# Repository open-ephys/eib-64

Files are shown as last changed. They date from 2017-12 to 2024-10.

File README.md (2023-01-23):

# EIB-64
64-channel electrode interface board (EIB) with electrical and optical
stimulation. Designed for small animal (e.g. mouse) tetrode electrophysiology.
Compatible with [ONIX 64-Channel Headstage](https://github.com/open-ephys/onix-headstage-64) and [Shuttle
Drives](https://open-ephys.org/shuttledrive).

See [this spreadsheet](https://docs.google.com/spreadsheets/d/1WYDymxNqGRtFPxn69H9JzeMgePpXcFSPHiWJYBE0lu4/edit?usp=sharing) for channel map 

- 64x electrophysiology channels
- 2x optical stimulation outputs
- 1x electrical stimulator output

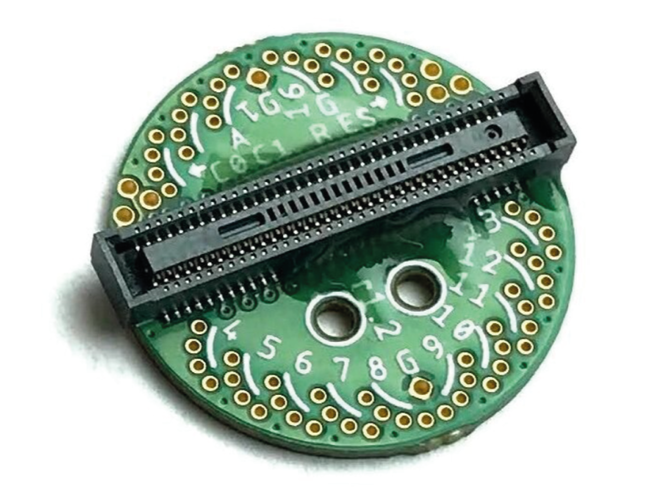
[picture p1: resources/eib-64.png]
EIB-64 revision 1.2


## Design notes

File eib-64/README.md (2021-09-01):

# EIB-64 PCB
Circuit design and manufacturing files for EIB-64.

## Bill of Materials
The BOM is located on [this google
sheet](https://docs.google.com/spreadsheets/d/1vJ3K68Tzy18eBl7zj2bWWYmF2zrh3wpJbKvRicM5Wa0/edit?usp=sharing)

## Pinout
The EIB pinout (ADC input mapping, stimulation connections, etc) is located on
[this google
sheet](https://docs.google.com/spreadsheets/d/11wRDYOqHN5lPb03yUdfXfK0zvaDYsVetplaNK-R90Gg/edit#gid=0)

## Tetrode Connectorization
This EIB uses Neuralynx ["small" gold
pins](https://neuralynx.com/hardware/small-eib-pins) to attach tetrode wires.
Usage instructions are provided in the [Neuralynx EIB pin
Manual](https://neuralynx.com/documents/EIB%20Pins%20Manual.pdf).

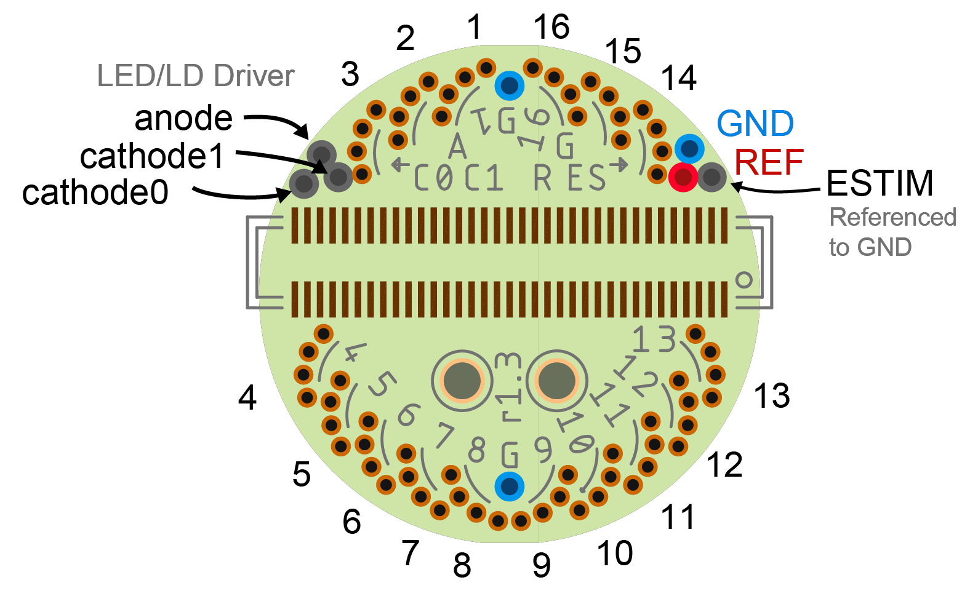
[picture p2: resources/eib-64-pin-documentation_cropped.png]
EIB-64 pinout


## Manufacturing Requirments
- 4 layer PCB (outer layers provide sheilding)
- 0.6-0.8 mm total thickness
- Immersion gold plating (ENIG) is required. 
- In order for the gold pins to properly fit in the designated vias, they must
  have a _plated_ inner diameter of 12±2 mil (0.3048±0.0508 mm). 

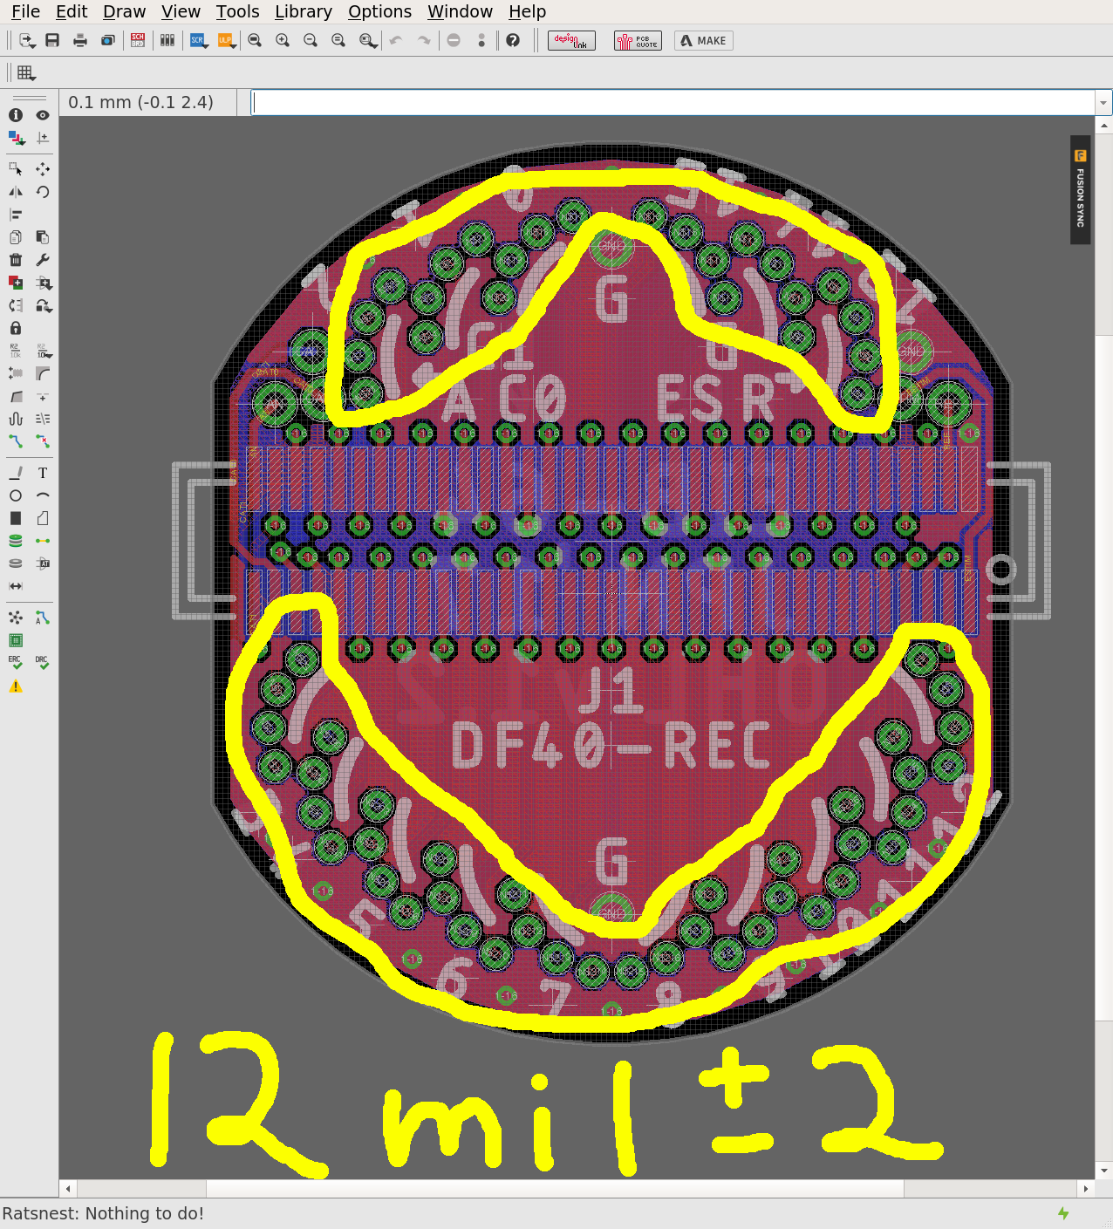
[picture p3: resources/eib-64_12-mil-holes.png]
Required via diametersEIB-64 pinout


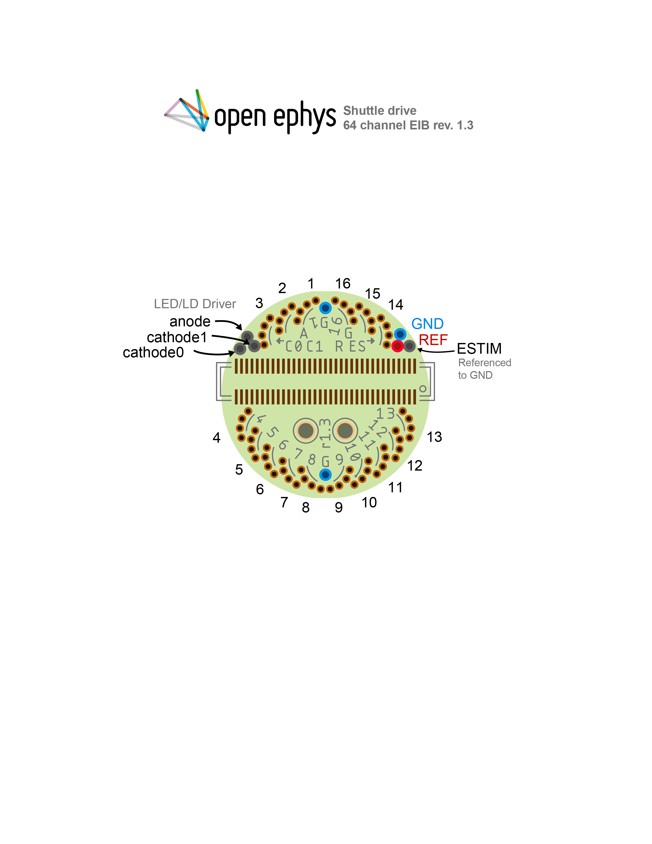
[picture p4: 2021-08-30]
resources/eib-64-pin-documentation.png

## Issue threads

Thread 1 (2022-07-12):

Mismatch between EIB pdf and linked mapping in doc

ablot, 2022-07-12:
In the onix documentation and in the readme.md the pin mapping points to this google doc: https://docs.google.com/spreadsheets/d/11wRDYOqHN5lPb03yUdfXfK0zvaDYsVetplaNK-R90Gg

In the google document, DF40 pin 37 is TT4B but in this repository, DF40 pin 37 is  LRG_GP SHLD_A. This is true for both eib-64/eib-64/eib-64.sch and the pdf version.

It might be a version issue. The pdf and sch files indicate REV 1.3 and the mapping google doc rev 1.2. If that's the case, where can I find the rev1.2 schematics?

ablot, 2022-07-12:
There is an other issue on the google doc. The nanoZ pin for TT14C is replaced by some wrongly copy/pasted text ("The EIB pinout (ephys input mapping, stimulation connections, etc) is located on this google sheet")

jonnew, 2022-07-22:
- Fixed the nanoZ TT14C copy/paste error
- Added tag for rev. 1.2 that went into production (https://github.com/open-ephys/eib-64/releases/tag/rev-1.2)
- I believe your EIB should be rev 1.2 (you can check the silk screen) and the spreadsheet mapping should now be correct.

Closed 2022-07-22.

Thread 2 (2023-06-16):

About 32-ch EIB for lack of a better place

ChucklesOnGitHub, 2023-06-16:
Regarding EIBs in general (see those available https://open-ephys.org/drive-implant/64-channel-eib-lyfw2)

- Hole size should be consistent across EIBs (at least of same size and application)
- 32-ch EIB does not have labels on the bottom side which make tetrode insertion and pinning much easier

jonnew, 2024-03-01:
Can you explain the second point, I don't understand it.

ChucklesOnGitHub, 2024-03-01:
This was me porting your comments from Discord during TENSS last year, so no idea what you were facing exactly :/

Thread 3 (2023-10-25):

64ch EIB schematics for channel mapping not in main

ChucklesOnGitHub, 2023-10-25:
User pointed out the following:
File [eib-64.brd](https://github.com/open-ephys/eib-64/blob/main/eib-64/eib-64.brd) does not match the [channel map](https://docs.google.com/spreadsheets/d/1WYDymxNqGRtFPxn69H9JzeMgePpXcFSPHiWJYBE0lu4/edit#gid=0).

- On one side the file shows pad 69 routing to a channel/pin and pad 70 going to the reference (when the channel map lists pin 69 as a reference and pin 70 as the ground)

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

- On the other side it likewise shows pad 36 going to an anode (which matches the channel map), but pad 37 going to ground (when the channel map routes it to a channel/pin).

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

On a physical EIB the routing is correct with regards to the channel map: REF is connected to pin 69 and GND to pin 70. - i've now realized what it is, I must have been looking at a r1.2

It would seem the file does not match the boards?

This made me realize the channel map has to be updated to read v1.3 and have picture of EIB v1.3 since the current production version is 1.3 and not 1.2 - I can handle this but not the above.

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

ChucklesOnGitHub, 2023-10-25:
I just realized the channel map for r1.3 is a different one, and that would solve it. Can you confirm so I can update the channel map google sheets?
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

jonnew, 2023-10-25:
We should deprecate 1.3 because it was never put in production (not that is
compatible with headstage rev 1.4, which also was never produced)

On Wed, Oct 25, 2023 at 11:26 AM Ceci Herbert ***@***.***>
wrote:

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

jonnew, 2024-03-01:
In any case, I think we need to role back HEAD commit on this repo to 1.2 since its all that will ever be made. Additionally, we need a more easy to follow pin mapping picture which has a front view image of the headstage with each of the DF40 pins labeled and each individual pin hole labelled.

ChucklesOnGitHub, 2024-03-08:
hi @jonnew I have in my hand an EIB that says r1.3, which as far as I understand is the same as r1.2 with an extra hole

ChucklesOnGitHub, 2024-03-20:
The correct production files are in the corresponding branch, the issue is solved by merging.

Just for reassurance, here is the correct mapping file of the EIB that is currently in production.
[eib-64_schematic.pdf](https://github.com/open-ephys/eib-64/files/14671609/eib-64_schematic.pdf)

and it matches both current production versions of onix hs-64 and low-profile-hs-64-spi
[hs-64-spi - schematic.pdf](https://github.com/open-ephys/eib-64/files/14671615/hs-64-spi.-.schematic.pdf)
[headstage-64_schematic.pdf](https://github.com/open-ephys/eib-64/files/14671616/headstage-64_schematic.pdf)

I have updated the channel map google sheet accordingly and plan on making it more clear with updated pictures

ChucklesOnGitHub, 2024-03-22:
For users to know which is the current manufactured version in case they want to access schematics or cad files, the following need to be main:
Repo: eib-64 - Branch: hw-dev-rev1.3. Tag rev1.3
Repo: onix-headstage-64 - Branch: rev-1.3B Tag rev-1.3B

- Additionally, the schematic information table inside file "headstage-64_schematic.pdf" in repo onix-headstage-64 mistakenly reads "1.2B", and should read "1.3B" otherwise it is impossible to know the version with the file alone

Outstanding on unifying this topic across repos is:
- have a public repo with the current manufactured files for nanoz adapter 1.0 with the tag rev1.0
- tag the adapter-64 with tag rev1.0

jonnew, 2024-10-30:
As of right now:

- main is now the production branch
- The revision 1.3 release points to the current tip of main
- The incompatible version was move to rev-1.4-dev branch

@ChucklesOnGitHub please close this issue if this takes care of the problem

ChucklesOnGitHub, 2024-10-31:
The original issue that pertains to this repo is solved, thank you.

I have put other related issues in their respective repos:
- https://github.com/open-ephys/adapter-hirose-omnetics-64/issues/2
- https://github.com/open-ephys/onix-headstage-64/issues/4
- https://github.com/open-ephys/onix-headstage-64/issues/3

Outstanding since I don't have a repo in which to open an issue:
- have a public repo with the current manufactured files for nanoz adapter 1.0 with the tag rev1.0

Closed 2024-10-31.

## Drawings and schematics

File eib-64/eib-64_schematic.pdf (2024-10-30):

A

A

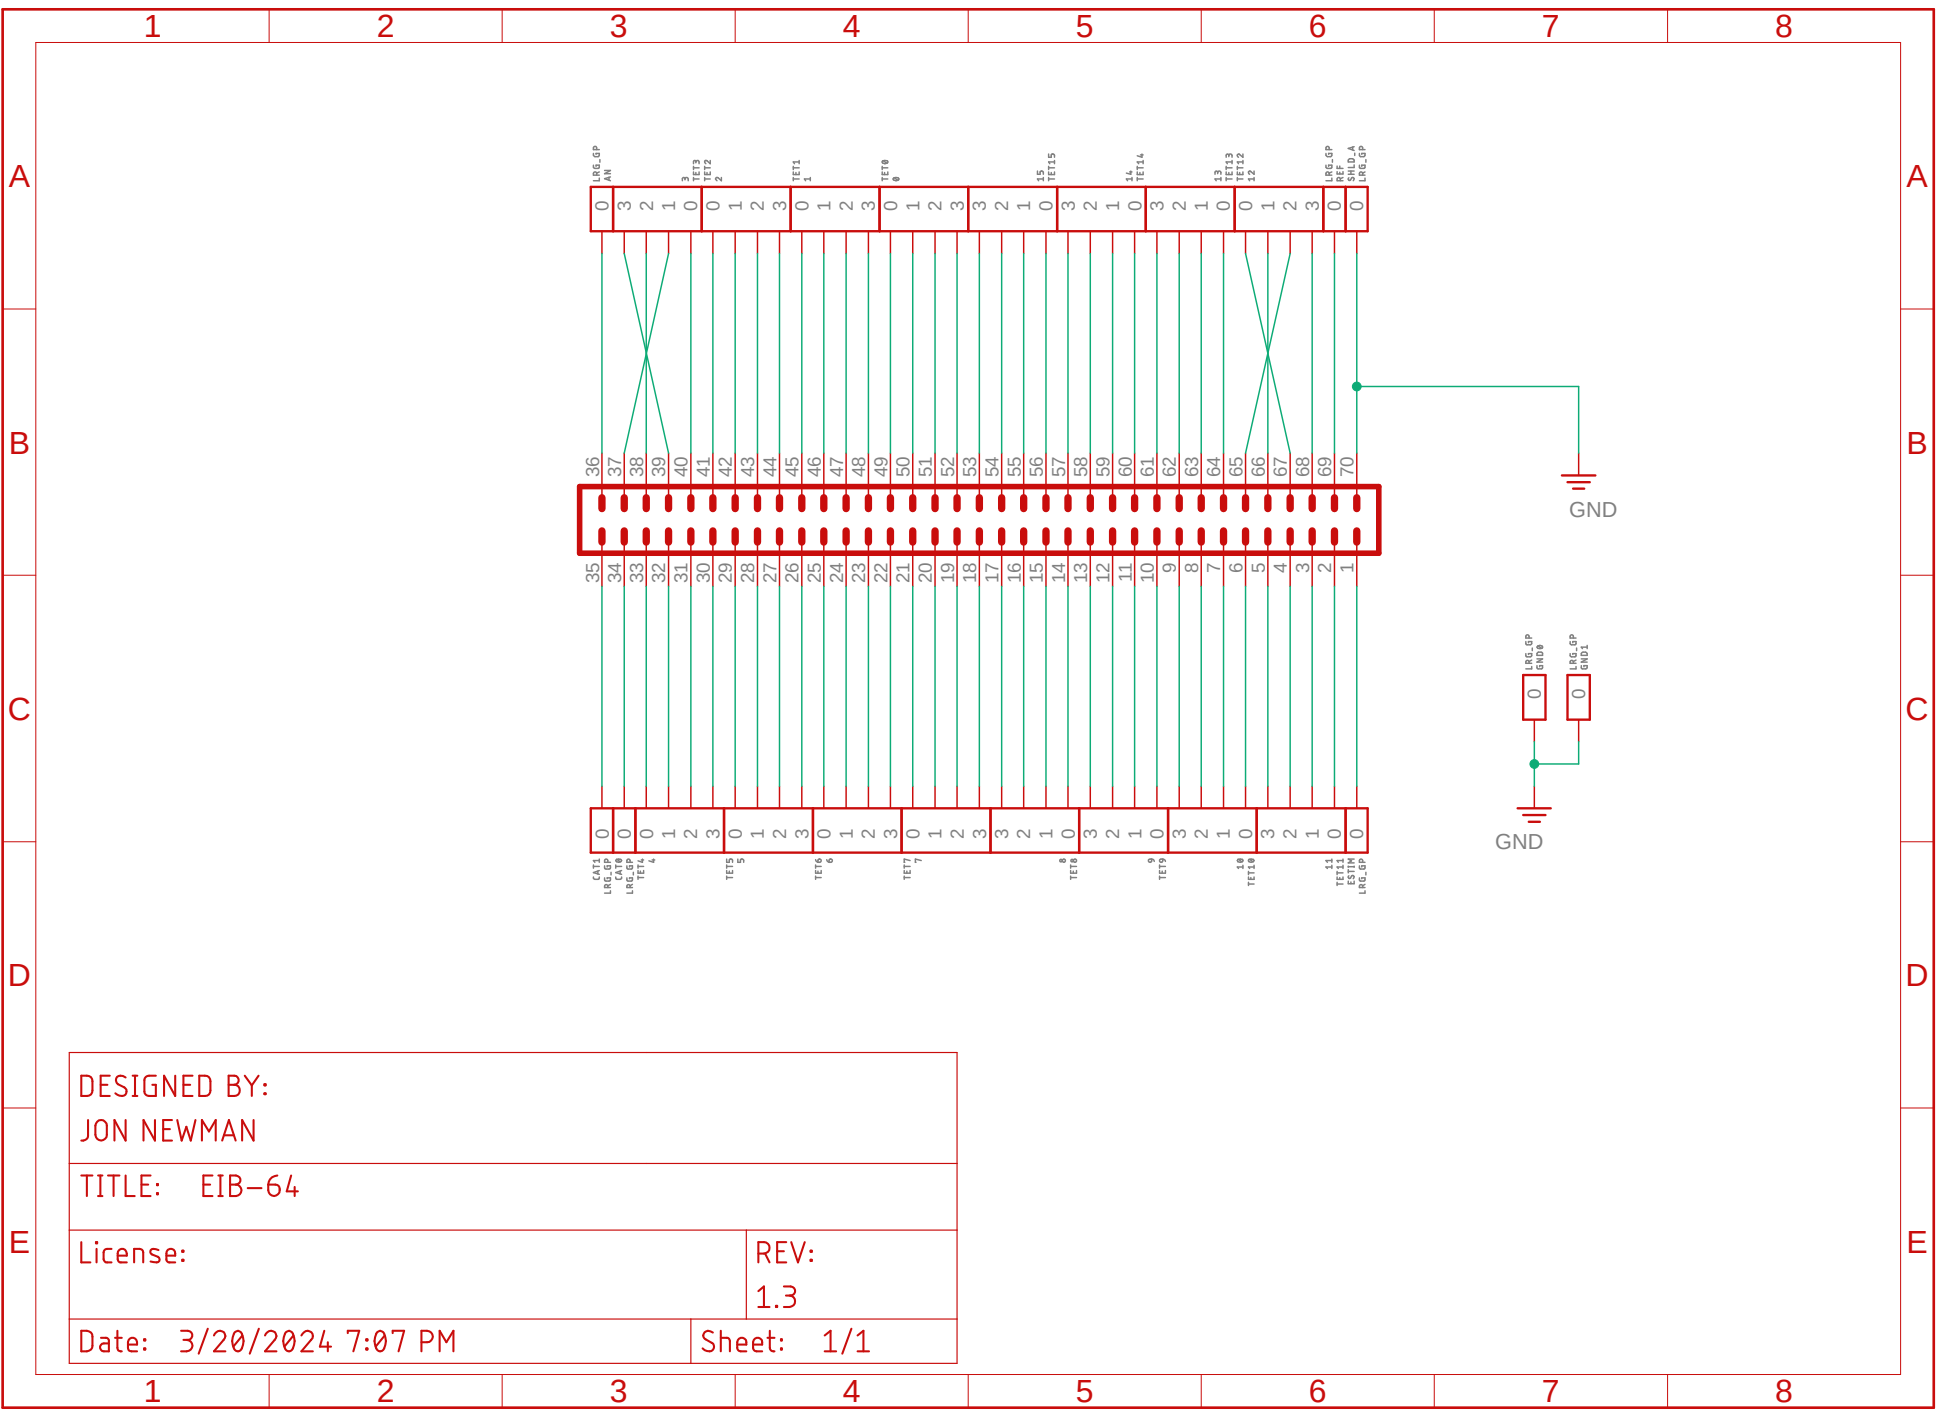
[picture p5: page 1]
GND; GND ⁰

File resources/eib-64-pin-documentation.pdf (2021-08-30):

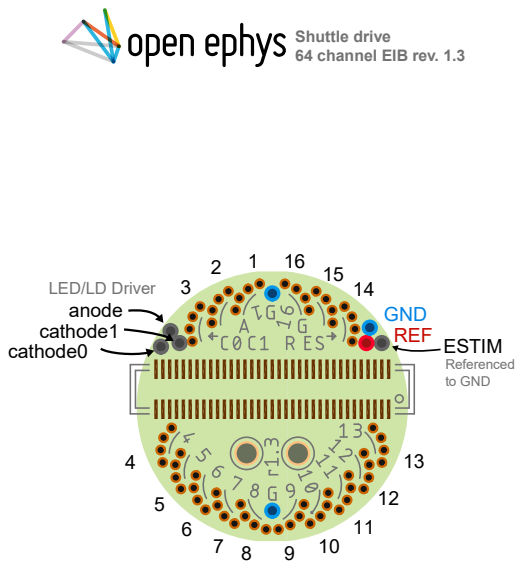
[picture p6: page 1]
GND REF ESTIM; cathode0; cathode1; anode; LED/LD Driver; Referenced to GND

Shuttle drive
64 channel EIB rev. 1.3

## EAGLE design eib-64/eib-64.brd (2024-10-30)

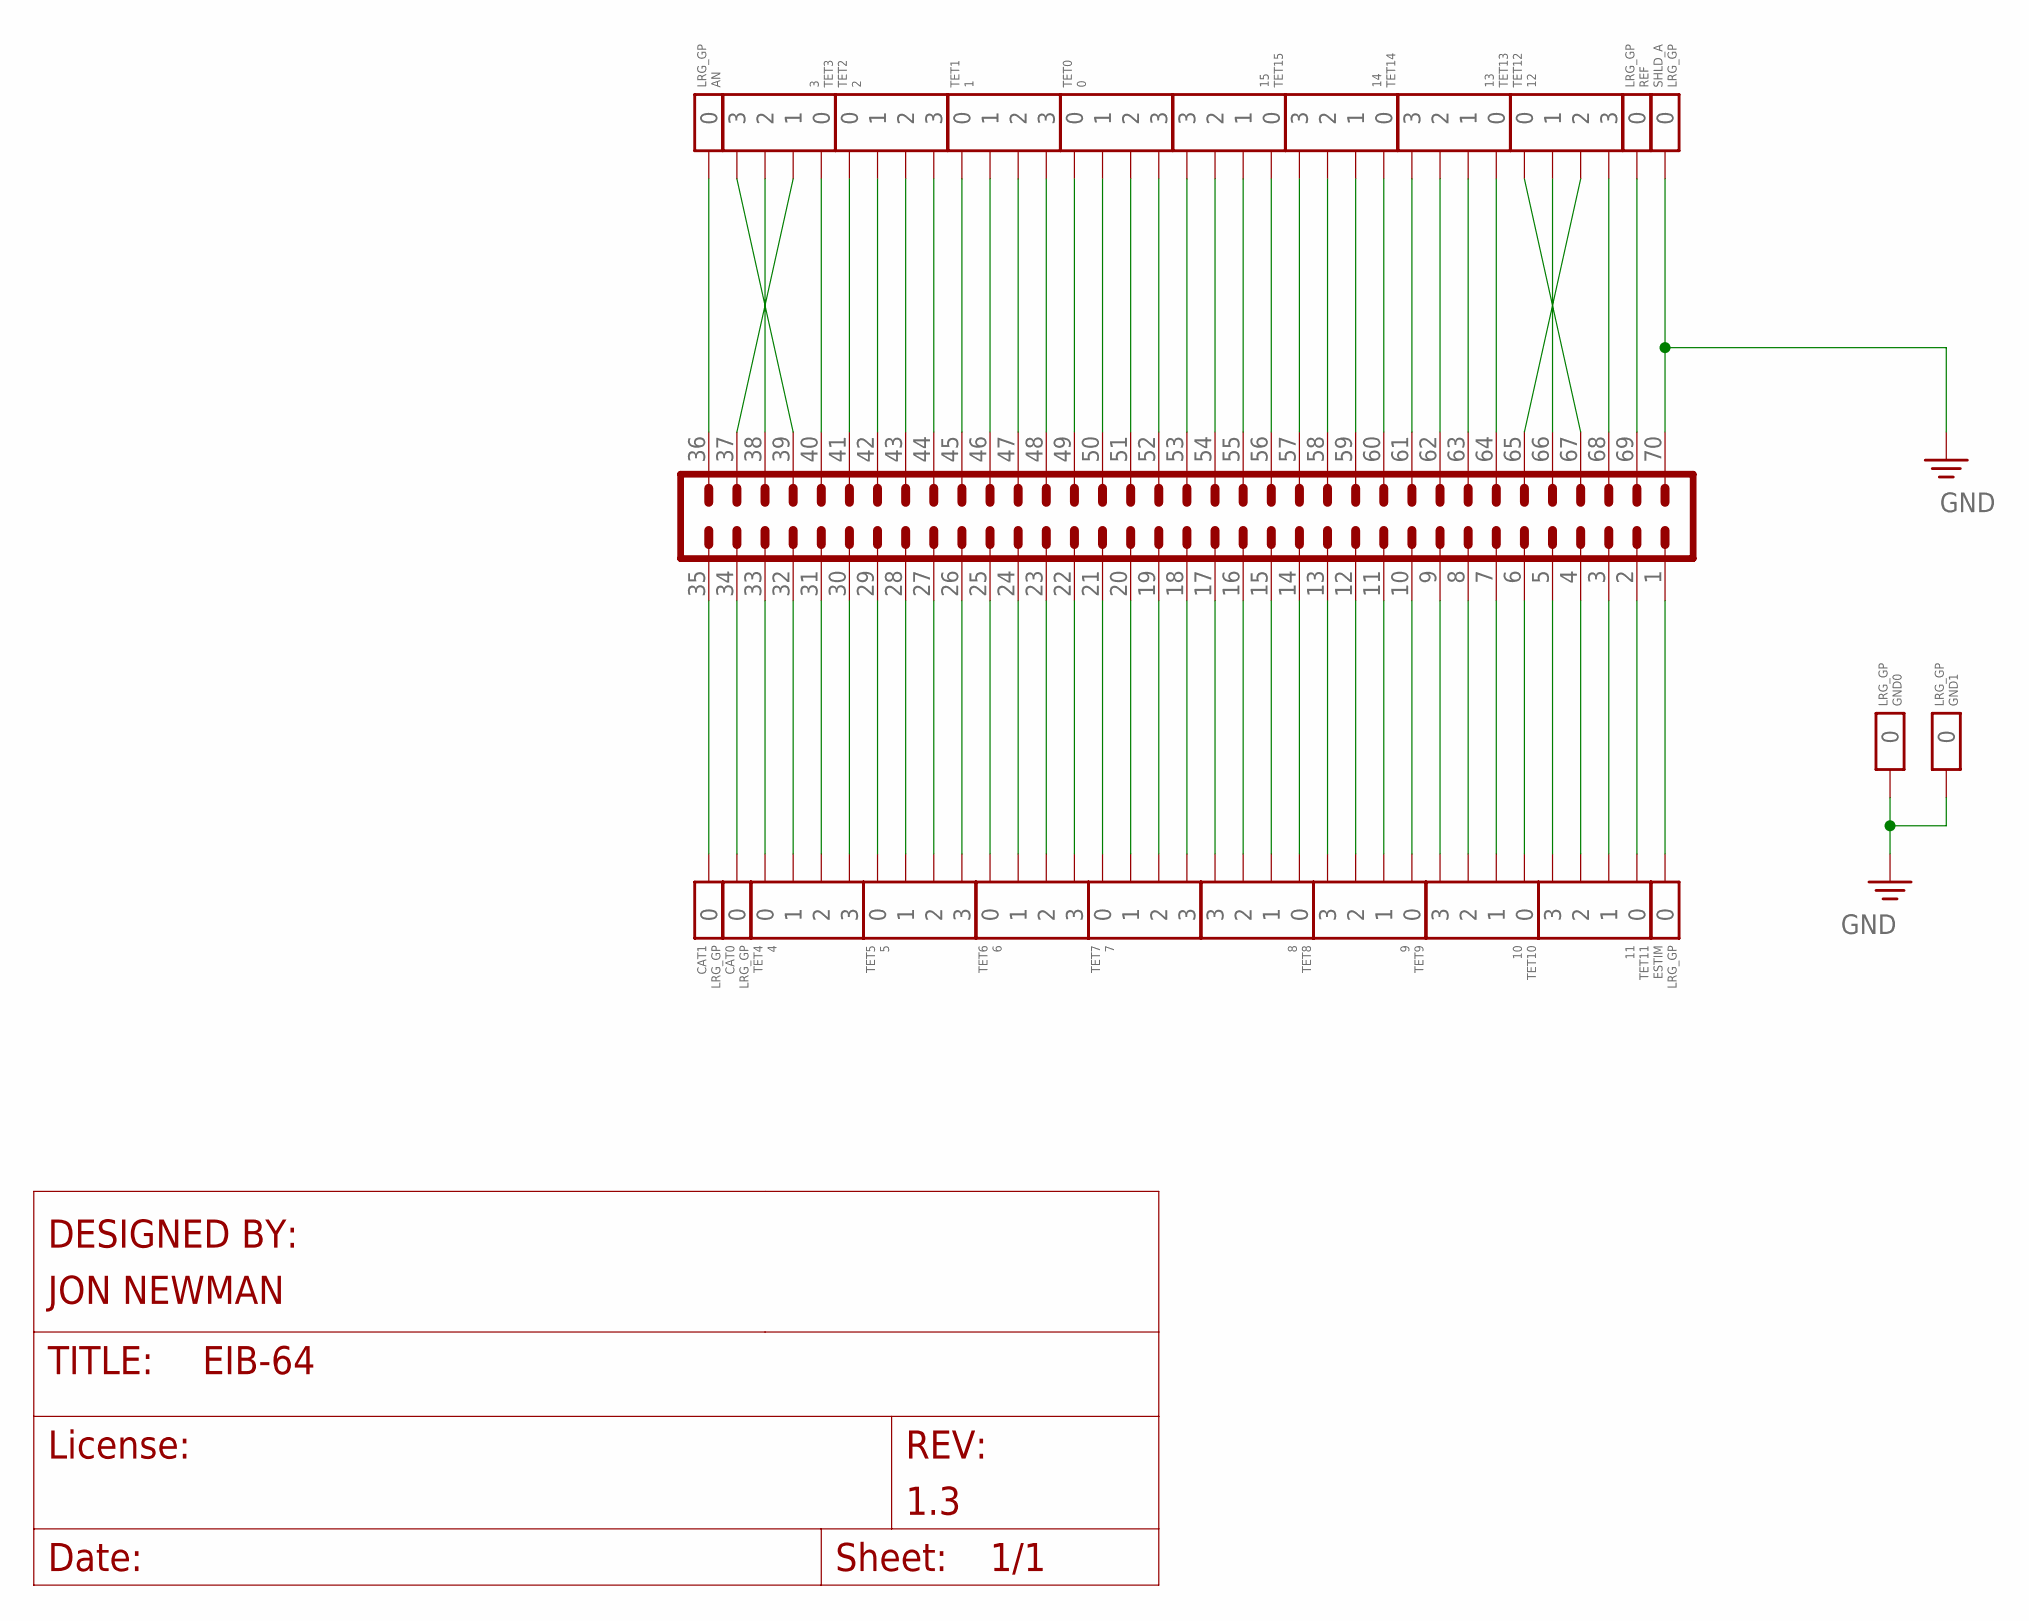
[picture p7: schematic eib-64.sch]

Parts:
AN: LRG_GP; GOLDPIN_0.5ID_0.7OD
CAT0, CAT1: LRG_GP; GOLDPIN_0.5ID_0.7OD
ESTIM: LRG_GP; GOLDPIN_0.5ID_0.7OD
GND0, GND1: LRG_GP; GOLDPIN_0.5ID_0.7OD
J1: DF40-REC; DF40-70REC
REF: LRG_GP; GOLDPIN_0.5ID_0.7OD
SHLD_A: LRG_GP; GOLDPIN_0.5ID_0.7OD
TET0: 0; TETRODE_0.3ID_LINEAR_MOUSE
TET1: 1; TETRODE_0.3ID_LINEAR_MOUSE
TET2: 2; TETRODE_0.3ID_LINEAR_MOUSE
TET3: 3; TETRODE_0.3ID_LINEAR_MOUSE
TET4: 4; TETRODE_0.3ID_LINEAR_MOUSE
TET5: 5; TETRODE_0.3ID_LINEAR_MOUSE
TET6: 6; TETRODE_0.3ID_LINEAR_MOUSE
TET7: 7; TETRODE_0.3ID_LINEAR_MOUSE
TET8: 8; TETRODE_0.3ID_LINEAR_MOUSE
TET9: 9; TETRODE_0.3ID_LINEAR_MOUSE
TET10: 10; TETRODE_0.3ID_LINEAR_MOUSE
TET11: 11; TETRODE_0.3ID_LINEAR_MOUSE
TET12: 12; TETRODE_0.3ID_LINEAR_MOUSE
TET13: 13; TETRODE_0.3ID_LINEAR_MOUSE
TET14: 14; TETRODE_0.3ID_LINEAR_MOUSE
TET15: 15; TETRODE_0.3ID_LINEAR_MOUSE

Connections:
AN: AN.P$1, J1.36
CAT0: CAT0.P$1, J1.34
CAT1: CAT1.P$1, J1.35
ESTIM: ESTIM.P$1, J1.1
GND: GND0.P$1, GND1.P$1, J1.70, SHLD_A.P$1
unnamed: J1.68, TET12.3
unnamed: J1.65, TET12.2
unnamed: J1.66, TET12.1
unnamed: J1.67, TET12.0
unnamed: J1.64, TET13.0
unnamed: J1.63, TET13.1
unnamed: J1.62, TET13.2
unnamed: J1.61, TET13.3
unnamed: J1.60, TET14.0
unnamed: J1.59, TET14.1
unnamed: J1.58, TET14.2
unnamed: J1.57, TET14.3
unnamed: J1.56, TET15.0
unnamed: J1.55, TET15.1
unnamed: J1.54, TET15.2
unnamed: J1.53, TET15.3
unnamed: J1.52, TET0.3
unnamed: J1.51, TET0.2
unnamed: J1.50, TET0.1
unnamed: J1.49, TET0.0
unnamed: J1.48, TET1.3
unnamed: J1.47, TET1.2
unnamed: J1.46, TET1.1
unnamed: J1.45, TET1.0
unnamed: J1.44, TET2.3
unnamed: J1.43, TET2.2
unnamed: J1.42, TET2.1
unnamed: J1.41, TET2.0
unnamed: J1.40, TET3.0
unnamed: J1.39, TET3.3
unnamed: J1.38, TET3.2
unnamed: J1.37, TET3.1
unnamed: J1.5, TET11.3
unnamed: J1.4, TET11.2
unnamed: J1.3, TET11.1
unnamed: J1.2, TET11.0
unnamed: J1.33, TET4.0
unnamed: J1.32, TET4.1
unnamed: J1.31, TET4.2
unnamed: J1.30, TET4.3
unnamed: J1.29, TET5.0
unnamed: J1.28, TET5.1
unnamed: J1.27, TET5.2
unnamed: J1.26, TET5.3
unnamed: J1.25, TET6.0
unnamed: J1.24, TET6.1
unnamed: J1.23, TET6.2
unnamed: J1.22, TET6.3
unnamed: J1.21, TET7.0
unnamed: J1.20, TET7.1
unnamed: J1.19, TET7.2
unnamed: J1.18, TET7.3
unnamed: J1.17, TET8.3
unnamed: J1.16, TET8.2
unnamed: J1.15, TET8.1
unnamed: J1.14, TET8.0
unnamed: J1.13, TET9.3
unnamed: J1.12, TET9.2
unnamed: J1.11, TET9.1
unnamed: J1.10, TET9.0
unnamed: J1.9, TET10.3
unnamed: J1.8, TET10.2
unnamed: J1.7, TET10.1
unnamed: J1.6, TET10.0
REF: J1.69, REF.P$1

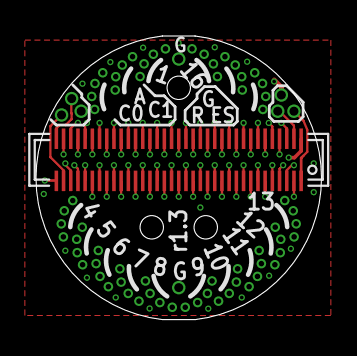
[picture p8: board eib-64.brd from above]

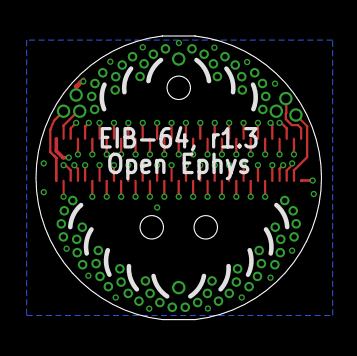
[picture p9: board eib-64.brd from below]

Board: 4 copper layers, 15.9 x 15.8 mm, 25 parts (8 on the bottom side), 70 nets.

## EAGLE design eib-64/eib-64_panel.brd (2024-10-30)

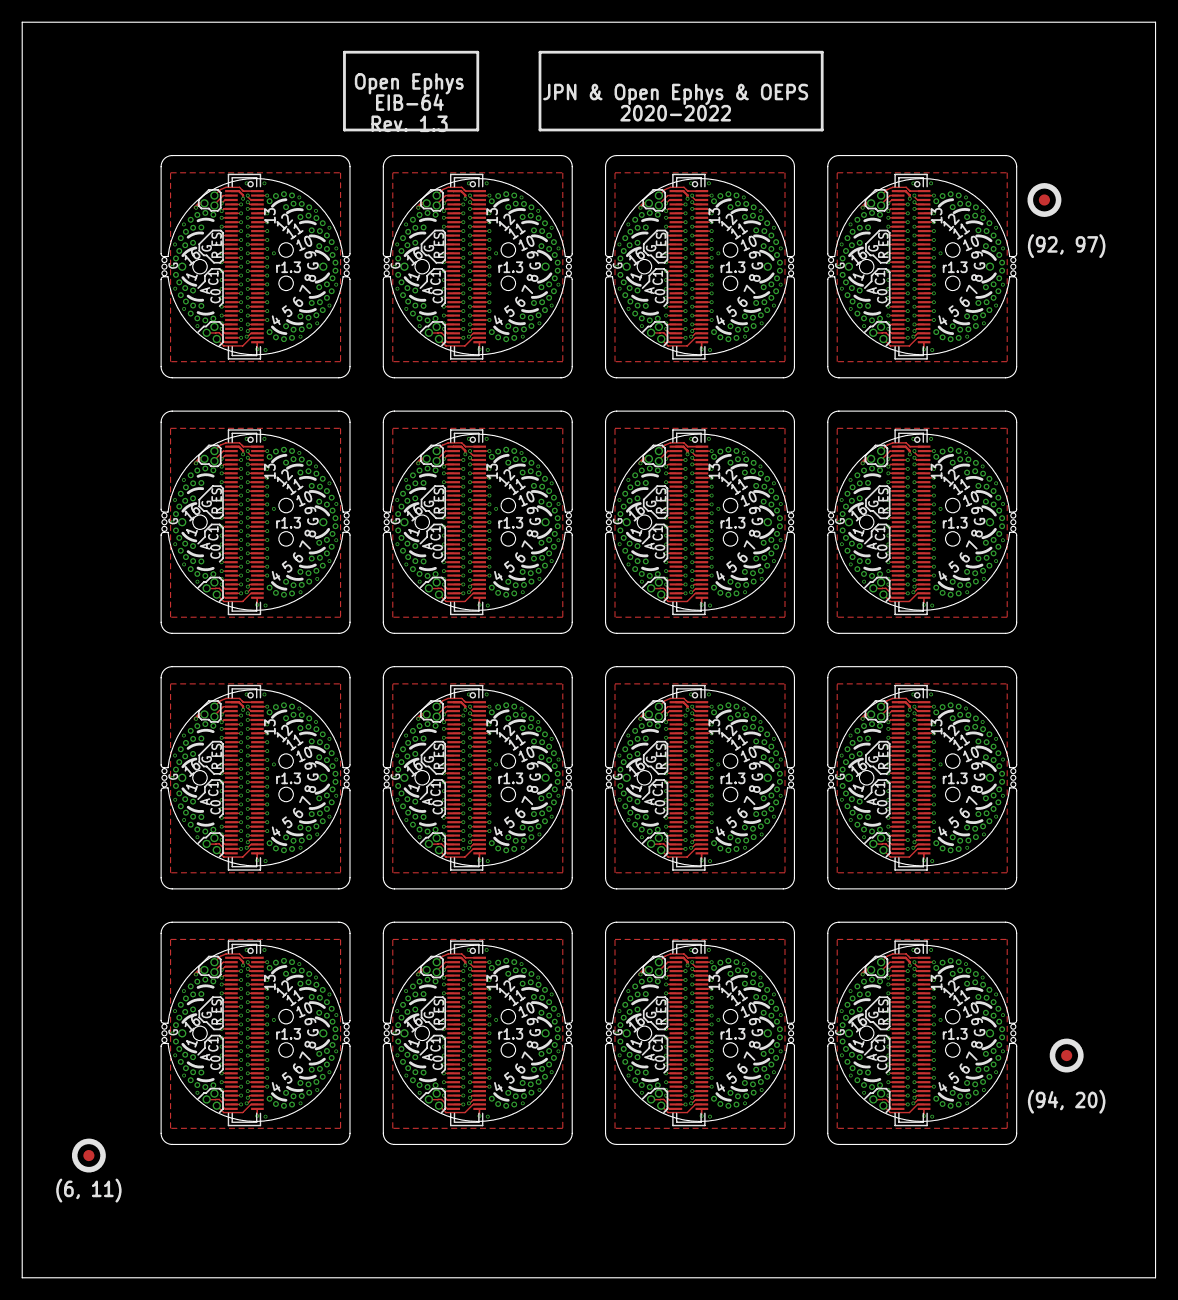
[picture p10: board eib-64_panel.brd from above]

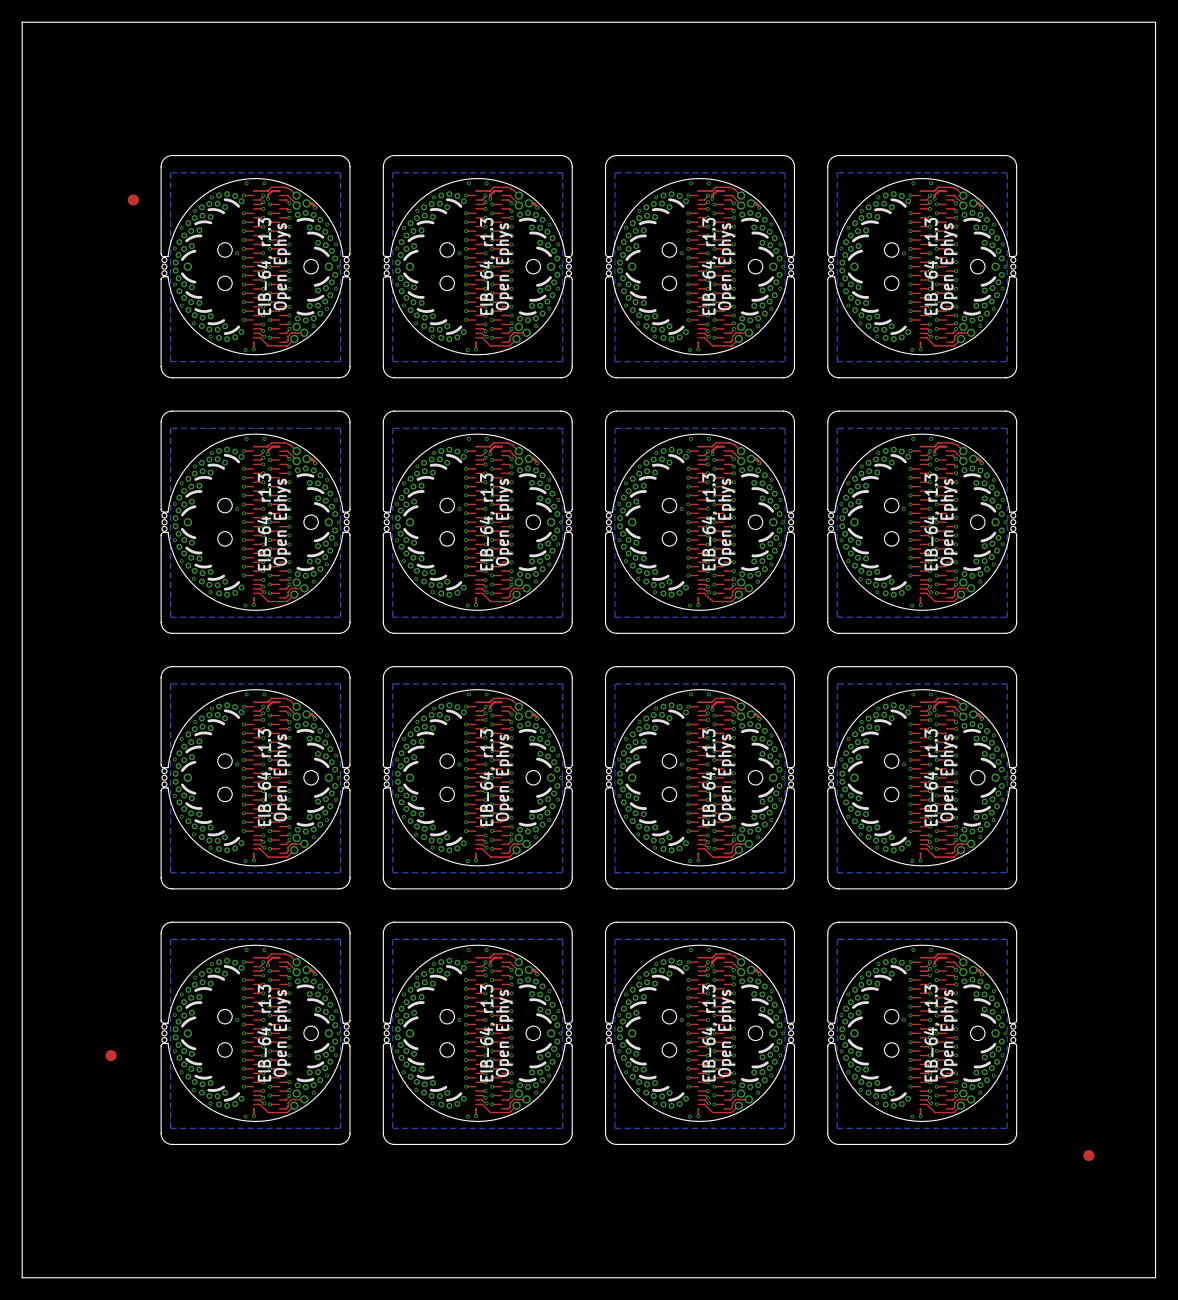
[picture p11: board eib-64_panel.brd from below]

Board: 4 copper layers, 102.0 x 113.0 mm, 403 parts (128 on the bottom side), 1120 nets.

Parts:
AN, AN1, AN2, AN3, AN4, AN5, AN6, AN7, AN8, AN9, AN10, AN11, AN12, AN13, AN14, AN15: LRG_GP; GOLDPIN_0.5ID_0.7OD
CAT0, CAT1, CAT2, CAT3, CAT4, CAT5, CAT6, CAT7, CAT8, CAT9, CAT10, CAT11, CAT12, CAT13, CAT14, CAT15, CAT16, CAT17, CAT18, CAT19, CAT20, CAT21, CAT22, CAT23, CAT24, CAT25, CAT26, CAT27, CAT28, CAT29, CAT30, CAT31: LRG_GP; GOLDPIN_0.5ID_0.7OD
E$1, E$2, E$4: FIDUCIAL
ESTIM, ESTIM1, ESTIM2, ESTIM3, ESTIM4, ESTIM5, ESTIM6, ESTIM7, ESTIM8, ESTIM9, ESTIM10, ESTIM11, ESTIM12, ESTIM13, ESTIM14, ESTIM15: LRG_GP; GOLDPIN_0.5ID_0.7OD
GND0, GND1, GND2, GND3, GND4, GND5, GND6, GND7, GND8, GND9, GND10, GND11, GND12, GND13, GND14, GND15, GND16, GND17, GND18, GND19, GND20, GND21, GND22, GND23, GND24, GND25, GND26, GND27, GND28, GND29, GND30, GND31: LRG_GP; GOLDPIN_0.5ID_0.7OD
J1, J2, J3, J4, J5, J6, J7, J8, J9, J10, J11, J12, J13, J14, J15, J16: DF40-REC; DF40-70REC
REF, REF1, REF2, REF3, REF4, REF5, REF6, REF7, REF8, REF9, REF10, REF11, REF12, REF13, REF14, REF15: LRG_GP; GOLDPIN_0.5ID_0.7OD
SHLD_A, SHLD_A1, SHLD_A2, SHLD_A3, SHLD_A4, SHLD_A5, SHLD_A6, SHLD_A7, SHLD_A8, SHLD_A9, SHLD_A10, SHLD_A11, SHLD_A12, SHLD_A13, SHLD_A14, SHLD_A15: LRG_GP; GOLDPIN_0.5ID_0.7OD
TET0, TET16, TET32, TET48, TET64, TET80, TET96, TET112, TET128, TET144, TET160, TET176, TET192, TET208, TET224, TET240: 0; TETRODE_0.3ID_LINEAR_MOUSE
TET1, TET17, TET33, TET49, TET65, TET81, TET97, TET113, TET129, TET145, TET161, TET177, TET193, TET209, TET225, TET241: 1; TETRODE_0.3ID_LINEAR_MOUSE
TET2, TET18, TET34, TET50, TET66, TET82, TET98, TET114, TET130, TET146, TET162, TET178, TET194, TET210, TET226, TET242: 2; TETRODE_0.3ID_LINEAR_MOUSE
TET3, TET19, TET35, TET51, TET67, TET83, TET99, TET115, TET131, TET147, TET163, TET179, TET195, TET211, TET227, TET243: 3; TETRODE_0.3ID_LINEAR_MOUSE
TET4, TET20, TET36, TET52, TET68, TET84, TET100, TET116, TET132, TET148, TET164, TET180, TET196, TET212, TET228, TET244: 4; TETRODE_0.3ID_LINEAR_MOUSE
TET5, TET21, TET37, TET53, TET69, TET85, TET101, TET117, TET133, TET149, TET165, TET181, TET197, TET213, TET229, TET245: 5; TETRODE_0.3ID_LINEAR_MOUSE
TET6, TET22, TET38, TET54, TET70, TET86, TET102, TET118, TET134, TET150, TET166, TET182, TET198, TET214, TET230, TET246: 6; TETRODE_0.3ID_LINEAR_MOUSE
TET7, TET23, TET39, TET55, TET71, TET87, TET103, TET119, TET135, TET151, TET167, TET183, TET199, TET215, TET231, TET247: 7; TETRODE_0.3ID_LINEAR_MOUSE
TET8, TET31, TET47, TET63, TET79, TET95, TET111, TET127, TET143, TET159, TET175, TET191, TET207, TET223, TET239, TET255: 8; TETRODE_0.3ID_LINEAR_MOUSE
TET9, TET30, TET46, TET62, TET78, TET94, TET110, TET126, TET142, TET158, TET174, TET190, TET206, TET222, TET238, TET254: 9; TETRODE_0.3ID_LINEAR_MOUSE
TET10, TET29, TET45, TET61, TET77, TET93, TET109, TET125, TET141, TET157, TET173, TET189, TET205, TET221, TET237, TET253: 10; TETRODE_0.3ID_LINEAR_MOUSE
TET11, TET28, TET44, TET60, TET76, TET92, TET108, TET124, TET140, TET156, TET172, TET188, TET204, TET220, TET236, TET252: 11; TETRODE_0.3ID_LINEAR_MOUSE
TET12, TET27, TET43, TET59, TET75, TET91, TET107, TET123, TET139, TET155, TET171, TET187, TET203, TET219, TET235, TET251: 12; TETRODE_0.3ID_LINEAR_MOUSE
TET13, TET26, TET42, TET58, TET74, TET90, TET106, TET122, TET138, TET154, TET170, TET186, TET202, TET218, TET234, TET250: 13; TETRODE_0.3ID_LINEAR_MOUSE
TET14, TET25, TET41, TET57, TET73, TET89, TET105, TET121, TET137, TET153, TET169, TET185, TET201, TET217, TET233, TET249: 14; TETRODE_0.3ID_LINEAR_MOUSE
TET15, TET24, TET40, TET56, TET72, TET88, TET104, TET120, TET136, TET152, TET168, TET184, TET200, TET216, TET232, TET248: 15; TETRODE_0.3ID_LINEAR_MOUSE

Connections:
AN: AN.P$1, J1.36
AN1: AN1.P$1, J2.36
AN2: AN2.P$1, J3.36
AN3: AN3.P$1, J4.36
AN4: AN4.P$1, J5.36
AN5: AN5.P$1, J6.36
AN6: AN6.P$1, J7.36
AN7: AN7.P$1, J8.36
AN8: AN8.P$1, J9.36
AN9: AN9.P$1, J10.36
AN10: AN10.P$1, J11.36
AN11: AN11.P$1, J12.36
AN12: AN12.P$1, J13.36
AN13: AN13.P$1, J14.36
AN14: AN14.P$1, J15.36
AN15: AN15.P$1, J16.36
CAT0: CAT0.P$1, J1.34
CAT1: CAT1.P$1, J1.35
CAT2: CAT2.P$1, J2.34
CAT3: CAT3.P$1, J2.35
CAT4: CAT4.P$1, J3.34
CAT5: CAT5.P$1, J3.35
CAT6: CAT6.P$1, J4.34
CAT7: CAT7.P$1, J4.35
CAT8: CAT8.P$1, J5.34
CAT9: CAT9.P$1, J5.35
CAT10: CAT10.P$1, J6.34
CAT11: CAT11.P$1, J6.35
CAT12: CAT12.P$1, J7.34
CAT13: CAT13.P$1, J7.35
CAT14: CAT14.P$1, J8.34
CAT15: CAT15.P$1, J8.35
CAT16: CAT16.P$1, J9.34
CAT17: CAT17.P$1, J9.35
CAT18: CAT18.P$1, J10.34
CAT19: CAT19.P$1, J10.35
CAT20: CAT20.P$1, J11.34
CAT21: CAT21.P$1, J11.35
CAT22: CAT22.P$1, J12.34
CAT23: CAT23.P$1, J12.35
CAT24: CAT24.P$1, J13.34
CAT25: CAT25.P$1, J13.35
CAT26: CAT26.P$1, J14.34
CAT27: CAT27.P$1, J14.35
CAT28: CAT28.P$1, J15.34
CAT29: CAT29.P$1, J15.35
CAT30: CAT30.P$1, J16.34
CAT31: CAT31.P$1, J16.35
ESTIM: ESTIM.P$1, J1.1
ESTIM1: ESTIM1.P$1, J2.1
ESTIM2: ESTIM2.P$1, J3.1
ESTIM3: ESTIM3.P$1, J4.1
ESTIM4: ESTIM4.P$1, J5.1
ESTIM5: ESTIM5.P$1, J6.1
ESTIM6: ESTIM6.P$1, J7.1
ESTIM7: ESTIM7.P$1, J8.1
ESTIM8: ESTIM8.P$1, J9.1
ESTIM9: ESTIM9.P$1, J10.1
ESTIM10: ESTIM10.P$1, J11.1
ESTIM11: ESTIM11.P$1, J12.1
ESTIM12: ESTIM12.P$1, J13.1
ESTIM13: ESTIM13.P$1, J14.1
ESTIM14: ESTIM14.P$1, J15.1
ESTIM15: ESTIM15.P$1, J16.1
GND: GND0.P$1, GND1.P$1, J1.70, SHLD_A.P$1
GND1: GND2.P$1, GND3.P$1, J2.70, SHLD_A1.P$1
GND2: GND4.P$1, GND5.P$1, J3.70, SHLD_A2.P$1
GND3: GND6.P$1, GND7.P$1, J4.70, SHLD_A3.P$1
GND4: GND8.P$1, GND9.P$1, J5.70, SHLD_A4.P$1
GND5: GND10.P$1, GND11.P$1, J6.70, SHLD_A5.P$1
GND6: GND12.P$1, GND13.P$1, J7.70, SHLD_A6.P$1
GND7: GND14.P$1, GND15.P$1, J8.70, SHLD_A7.P$1
GND8: GND16.P$1, GND17.P$1, J9.70, SHLD_A8.P$1
GND9: GND18.P$1, GND19.P$1, J10.70, SHLD_A9.P$1
GND10: GND20.P$1, GND21.P$1, J11.70, SHLD_A10.P$1
GND11: GND22.P$1, GND23.P$1, J12.70, SHLD_A11.P$1
GND12: GND24.P$1, GND25.P$1, J13.70, SHLD_A12.P$1
GND13: GND26.P$1, GND27.P$1, J14.70, SHLD_A13.P$1
GND14: GND28.P$1, GND29.P$1, J15.70, SHLD_A14.P$1
GND15: GND30.P$1, GND31.P$1, J16.70, SHLD_A15.P$1
unnamed: J1.68, TET12.3
unnamed: J1.65, TET12.2
unnamed: J1.66, TET12.1
unnamed: J1.67, TET12.0
unnamed: J1.64, TET13.0
unnamed: J1.63, TET13.1
unnamed: J1.62, TET13.2
unnamed: J1.61, TET13.3
unnamed: J1.60, TET14.0
unnamed: J1.59, TET14.1
unnamed: J1.58, TET14.2
unnamed: J1.57, TET14.3
unnamed: J1.56, TET15.0
unnamed: J1.55, TET15.1
unnamed: J1.54, TET15.2
unnamed: J1.53, TET15.3
unnamed: J1.52, TET0.3
unnamed: J1.51, TET0.2
unnamed: J1.50, TET0.1
unnamed: J1.49, TET0.0
unnamed: J1.48, TET1.3
unnamed: J1.47, TET1.2
unnamed: J1.46, TET1.1
unnamed: J1.45, TET1.0
unnamed: J1.44, TET2.3
unnamed: J1.43, TET2.2
unnamed: J1.42, TET2.1
unnamed: J1.41, TET2.0
unnamed: J1.40, TET3.0
unnamed: J1.39, TET3.3
unnamed: J1.38, TET3.2
unnamed: J1.37, TET3.1
unnamed: J1.5, TET11.3
unnamed: J1.4, TET11.2
unnamed: J1.3, TET11.1
unnamed: J1.2, TET11.0
unnamed: J2.33, TET20.0
unnamed: J2.32, TET20.1
unnamed: J2.31, TET20.2
unnamed: J2.30, TET20.3
unnamed: J2.29, TET21.0
unnamed: J2.28, TET21.1
unnamed: J2.27, TET21.2
unnamed: J2.26, TET21.3
unnamed: J2.25, TET22.0
unnamed: J2.24, TET22.1
unnamed: J2.23, TET22.2
unnamed: J2.22, TET22.3
unnamed: J2.21, TET23.0
unnamed: J2.20, TET23.1
unnamed: J2.19, TET23.2
unnamed: J2.18, TET23.3
unnamed: J2.17, TET31.3
unnamed: J2.16, TET31.2
unnamed: J2.15, TET31.1
unnamed: J2.14, TET31.0
unnamed: J2.13, TET30.3
unnamed: J2.12, TET30.2
unnamed: J2.11, TET30.1
unnamed: J2.10, TET30.0
unnamed: J2.9, TET29.3
unnamed: J2.8, TET29.2
unnamed: J2.7, TET29.1
unnamed: J2.6, TET29.0
unnamed: J2.68, TET27.3
unnamed: J2.66, TET27.1
unnamed: J2.64, TET26.0
unnamed: J2.63, TET26.1
unnamed: J2.62, TET26.2
unnamed: J2.61, TET26.3
unnamed: J2.60, TET25.0
unnamed: J2.59, TET25.1
unnamed: J2.58, TET25.2
unnamed: J2.57, TET25.3
unnamed: J2.56, TET24.0
unnamed: J2.55, TET24.1
unnamed: J2.54, TET24.2
unnamed: J2.53, TET24.3
unnamed: J2.52, TET16.3
unnamed: J2.51, TET16.2
unnamed: J2.50, TET16.1
unnamed: J2.49, TET16.0
unnamed: J2.48, TET17.3
unnamed: J2.47, TET17.2
unnamed: J2.46, TET17.1
unnamed: J2.45, TET17.0
unnamed: J2.44, TET18.3
unnamed: J2.43, TET18.2
unnamed: J2.42, TET18.1
unnamed: J2.41, TET18.0
unnamed: J2.40, TET19.0
unnamed: J2.38, TET19.2
unnamed: J2.5, TET28.3
unnamed: J2.4, TET28.2
unnamed: J2.3, TET28.1
unnamed: J2.2, TET28.0
unnamed: J2.65, TET27.2
unnamed: J2.67, TET27.0
unnamed: J2.39, TET19.3
unnamed: J2.37, TET19.1
unnamed: J3.33, TET36.0
unnamed: J3.32, TET36.1
unnamed: J3.31, TET36.2
unnamed: J3.30, TET36.3
unnamed: J3.29, TET37.0
unnamed: J3.28, TET37.1
unnamed: J3.27, TET37.2
unnamed: J3.26, TET37.3
unnamed: J3.25, TET38.0
unnamed: J3.24, TET38.1
unnamed: J3.23, TET38.2
unnamed: J3.22, TET38.3
unnamed: J3.21, TET39.0
unnamed: J3.20, TET39.1
unnamed: J3.19, TET39.2
unnamed: J3.18, TET39.3
unnamed: J3.17, TET47.3
unnamed: J3.16, TET47.2
unnamed: J3.15, TET47.1
unnamed: J3.14, TET47.0
unnamed: J3.13, TET46.3
unnamed: J3.12, TET46.2
unnamed: J3.11, TET46.1
unnamed: J3.10, TET46.0
unnamed: J3.9, TET45.3
unnamed: J3.8, TET45.2
unnamed: J3.7, TET45.1
unnamed: J3.6, TET45.0
unnamed: J3.68, TET43.3
unnamed: J3.66, TET43.1
unnamed: J3.64, TET42.0
unnamed: J3.63, TET42.1
unnamed: J3.62, TET42.2
unnamed: J3.61, TET42.3
unnamed: J3.60, TET41.0
unnamed: J3.59, TET41.1
unnamed: J3.58, TET41.2
unnamed: J3.57, TET41.3
unnamed: J3.56, TET40.0
unnamed: J3.55, TET40.1
unnamed: J3.54, TET40.2
unnamed: J3.53, TET40.3
unnamed: J3.52, TET32.3
unnamed: J3.51, TET32.2
unnamed: J3.50, TET32.1
unnamed: J3.49, TET32.0
unnamed: J3.48, TET33.3
unnamed: J3.47, TET33.2
unnamed: J3.46, TET33.1
unnamed: J3.45, TET33.0
unnamed: J3.44, TET34.3
unnamed: J3.43, TET34.2
unnamed: J3.42, TET34.1
unnamed: J3.41, TET34.0
unnamed: J3.40, TET35.0
unnamed: J3.38, TET35.2
unnamed: J3.5, TET44.3
unnamed: J3.4, TET44.2
unnamed: J3.3, TET44.1
unnamed: J3.2, TET44.0
unnamed: J3.65, TET43.2
unnamed: J3.67, TET43.0
unnamed: J3.39, TET35.3
unnamed: J3.37, TET35.1
unnamed: J4.33, TET52.0
unnamed: J4.32, TET52.1
unnamed: J4.31, TET52.2
unnamed: J4.30, TET52.3
unnamed: J4.29, TET53.0
unnamed: J4.28, TET53.1
unnamed: J4.27, TET53.2
unnamed: J4.26, TET53.3
unnamed: J4.25, TET54.0
unnamed: J4.24, TET54.1
unnamed: J4.23, TET54.2
unnamed: J4.22, TET54.3
unnamed: J4.21, TET55.0
unnamed: J4.20, TET55.1
unnamed: J4.19, TET55.2
unnamed: J4.18, TET55.3
unnamed: J4.17, TET63.3
unnamed: J4.16, TET63.2
unnamed: J4.15, TET63.1
unnamed: J4.14, TET63.0
unnamed: J4.13, TET62.3
unnamed: J4.12, TET62.2
unnamed: J4.11, TET62.1
unnamed: J4.10, TET62.0
unnamed: J4.9, TET61.3
unnamed: J4.8, TET61.2
unnamed: J4.7, TET61.1
unnamed: J4.6, TET61.0
unnamed: J4.68, TET59.3
unnamed: J4.66, TET59.1
unnamed: J4.64, TET58.0
unnamed: J4.63, TET58.1
unnamed: J4.62, TET58.2
unnamed: J4.61, TET58.3
unnamed: J1.33, TET4.0
unnamed: J1.32, TET4.1
unnamed: J1.31, TET4.2
unnamed: J1.30, TET4.3
unnamed: J1.29, TET5.0
unnamed: J1.28, TET5.1
unnamed: J1.27, TET5.2
unnamed: J1.26, TET5.3
unnamed: J1.25, TET6.0
unnamed: J1.24, TET6.1
unnamed: J1.23, TET6.2
unnamed: J1.22, TET6.3
unnamed: J1.21, TET7.0
unnamed: J1.20, TET7.1
unnamed: J1.19, TET7.2
unnamed: J1.18, TET7.3
unnamed: J1.17, TET8.3
unnamed: J1.16, TET8.2
unnamed: J1.15, TET8.1
unnamed: J1.14, TET8.0
unnamed: J1.13, TET9.3
unnamed: J1.12, TET9.2
unnamed: J1.11, TET9.1
unnamed: J1.10, TET9.0
unnamed: J1.9, TET10.3
unnamed: J1.8, TET10.2
unnamed: J1.7, TET10.1
unnamed: J1.6, TET10.0
unnamed: J4.60, TET57.0
unnamed: J4.59, TET57.1
unnamed: J4.58, TET57.2
unnamed: J4.57, TET57.3
unnamed: J4.56, TET56.0
unnamed: J4.55, TET56.1
unnamed: J4.54, TET56.2
unnamed: J4.53, TET56.3
unnamed: J4.52, TET48.3
unnamed: J4.51, TET48.2
unnamed: J4.50, TET48.1
unnamed: J4.49, TET48.0
unnamed: J4.48, TET49.3
unnamed: J4.47, TET49.2
unnamed: J4.46, TET49.1
unnamed: J4.45, TET49.0
unnamed: J4.44, TET50.3
unnamed: J4.43, TET50.2
unnamed: J4.42, TET50.1
unnamed: J4.41, TET50.0
unnamed: J4.40, TET51.0
unnamed: J4.38, TET51.2
unnamed: J4.5, TET60.3
unnamed: J4.4, TET60.2
unnamed: J4.3, TET60.1
unnamed: J4.2, TET60.0
unnamed: J4.65, TET59.2
unnamed: J4.67, TET59.0
unnamed: J4.39, TET51.3
unnamed: J4.37, TET51.1
unnamed: J5.33, TET68.0
unnamed: J5.32, TET68.1
unnamed: J5.31, TET68.2
unnamed: J5.30, TET68.3
unnamed: J5.29, TET69.0
unnamed: J5.28, TET69.1
unnamed: J5.27, TET69.2
unnamed: J5.26, TET69.3
unnamed: J5.25, TET70.0
unnamed: J5.24, TET70.1
unnamed: J5.23, TET70.2
unnamed: J5.22, TET70.3
unnamed: J5.21, TET71.0
unnamed: J5.20, TET71.1
unnamed: J5.19, TET71.2
unnamed: J5.18, TET71.3
unnamed: J5.17, TET79.3
unnamed: J5.16, TET79.2
unnamed: J5.15, TET79.1
unnamed: J5.14, TET79.0
unnamed: J5.13, TET78.3
unnamed: J5.12, TET78.2
unnamed: J5.11, TET78.1
unnamed: J5.10, TET78.0
unnamed: J5.9, TET77.3
unnamed: J5.8, TET77.2
unnamed: J5.7, TET77.1
unnamed: J5.6, TET77.0
unnamed: J5.68, TET75.3
unnamed: J5.66, TET75.1
unnamed: J5.64, TET74.0
unnamed: J5.63, TET74.1
unnamed: J5.62, TET74.2
unnamed: J5.61, TET74.3
unnamed: J5.60, TET73.0
unnamed: J5.59, TET73.1
unnamed: J5.58, TET73.2
unnamed: J5.57, TET73.3
unnamed: J5.56, TET72.0
unnamed: J5.55, TET72.1
unnamed: J5.54, TET72.2
unnamed: J5.53, TET72.3
unnamed: J5.52, TET64.3
unnamed: J5.51, TET64.2
unnamed: J5.50, TET64.1
unnamed: J5.49, TET64.0
unnamed: J5.48, TET65.3
unnamed: J5.47, TET65.2
unnamed: J5.46, TET65.1
unnamed: J5.45, TET65.0
unnamed: J5.44, TET66.3
unnamed: J5.43, TET66.2
unnamed: J5.42, TET66.1
unnamed: J5.41, TET66.0
unnamed: J5.40, TET67.0
unnamed: J5.38, TET67.2
unnamed: J5.5, TET76.3
unnamed: J5.4, TET76.2
unnamed: J5.3, TET76.1
unnamed: J5.2, TET76.0
unnamed: J5.65, TET75.2
unnamed: J5.67, TET75.0
unnamed: J5.39, TET67.3
unnamed: J5.37, TET67.1
unnamed: J6.33, TET84.0
unnamed: J6.32, TET84.1
unnamed: J6.31, TET84.2
unnamed: J6.30, TET84.3
unnamed: J6.29, TET85.0
unnamed: J6.28, TET85.1
unnamed: J6.27, TET85.2
unnamed: J6.26, TET85.3
unnamed: J6.25, TET86.0
unnamed: J6.24, TET86.1
unnamed: J6.23, TET86.2
unnamed: J6.22, TET86.3
unnamed: J6.21, TET87.0
unnamed: J6.20, TET87.1
unnamed: J6.19, TET87.2
unnamed: J6.18, TET87.3
unnamed: J6.17, TET95.3
unnamed: J6.16, TET95.2
unnamed: J6.15, TET95.1
unnamed: J6.14, TET95.0
unnamed: J6.13, TET94.3
unnamed: J6.12, TET94.2
unnamed: J6.11, TET94.1
unnamed: J6.10, TET94.0
unnamed: J6.9, TET93.3
unnamed: J6.8, TET93.2
unnamed: J6.7, TET93.1
unnamed: J6.6, TET93.0
unnamed: J6.68, TET91.3
unnamed: J6.66, TET91.1
unnamed: J6.64, TET90.0
unnamed: J6.63, TET90.1
unnamed: J6.62, TET90.2
unnamed: J6.61, TET90.3
unnamed: J6.60, TET89.0
unnamed: J6.59, TET89.1
unnamed: J6.58, TET89.2
unnamed: J6.57, TET89.3
unnamed: J6.56, TET88.0
unnamed: J6.55, TET88.1
unnamed: J6.54, TET88.2
unnamed: J6.53, TET88.3
unnamed: J6.52, TET80.3
unnamed: J6.51, TET80.2
unnamed: J6.50, TET80.1
unnamed: J6.49, TET80.0
unnamed: J6.48, TET81.3
unnamed: J6.47, TET81.2
unnamed: J6.46, TET81.1
unnamed: J6.45, TET81.0
unnamed: J6.44, TET82.3
unnamed: J6.43, TET82.2
unnamed: J6.42, TET82.1
unnamed: J6.41, TET82.0
unnamed: J6.40, TET83.0
unnamed: J6.38, TET83.2
unnamed: J6.5, TET92.3
unnamed: J6.4, TET92.2
unnamed: J6.3, TET92.1
unnamed: J6.2, TET92.0
unnamed: J6.65, TET91.2
unnamed: J6.67, TET91.0
unnamed: J6.39, TET83.3
unnamed: J6.37, TET83.1
unnamed: J7.33, TET100.0
unnamed: J7.32, TET100.1
unnamed: J7.31, TET100.2
unnamed: J7.30, TET100.3
unnamed: J7.29, TET101.0
unnamed: J7.28, TET101.1
unnamed: J7.27, TET101.2
unnamed: J7.26, TET101.3
unnamed: J7.25, TET102.0
unnamed: J7.24, TET102.1
unnamed: J7.23, TET102.2
unnamed: J7.22, TET102.3
unnamed: J7.21, TET103.0
unnamed: J7.20, TET103.1
unnamed: J7.19, TET103.2
unnamed: J7.18, TET103.3
unnamed: J7.17, TET111.3
unnamed: J7.16, TET111.2
unnamed: J7.15, TET111.1
unnamed: J7.14, TET111.0
unnamed: J7.13, TET110.3
unnamed: J7.12, TET110.2
unnamed: J7.11, TET110.1
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

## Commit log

2017-11-18 Created eib-64
    - Fits headstage-64
    - Also, put a keepout layer in eib-128 and eib-256 around the edge where
    the PCB makes contact with the drive body
    [eib-64.GBL, eib-64.GBO, eib-64.GBS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]
2017-12-03 Fixed missing 1.8v power intput to serializer in headstage-64
    - Added values to components missing them
    - Completed ERC and DRC
    - Should be ready for fab pending final checks by other ppl
    [eib-64.brd]
2018-04-05 Reduced size of eib-64
    - Also created v-cut panelized board with 12 eibs
    [eib-64.brd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]
2018-04-15 Lots of small fixes and cleanup
    - Taking care of little issues that have been bothering me
    - Dediated serdes interface board moved to deprecated
    - Non-serialized headstage moved to deprecated
    - Deleted top-level datasheets directory which does not really
    apply to anything anymore
    - Added pdfs versions of board schematics so that eagle is not
    needed to see them.
    - Small fixes to test-boards: High power LEDs moved to bottom to prevent
    blinding ppl. Silkscreen improved. License updated. Etc. Gerbers
    updated.
    - Removed random deprecated design files where I found them.
2018-04-15 More cleanup
    - Add stencil gerbers for all eibs and eib panels
    - Remove unused intermediate design files
    [eib-64_panel.GBL, eib-64_panel.GBO, eib-64_panel.GBS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]
2018-04-19 Updated eib-64 to meet seeed low-cost spec
    - 8 mil trace/pour spacing
    - Added stencil gerbers as well
    [eib-64.brd, eib-64_panel.brd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]
2018-08-27 eib-64 rev. 1.1
    - Fits latest shuttle drive reatining feature.
    [eib-64.GBL, eib-64.GBO, eib-64.GBS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]
2019-03-05 Increased size of eib-64 panel
    - To fit minimal requirement of 7cm x 7cm for JLCPCB
    [eib-64_panel.GBL, eib-64_panel.GBO, eib-64_panel.GBS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]
2019-07-28 Updates to eib-64 for latest shuttle drives
    - Decreased outer diameter
    - Removed flat spots because they are not required anymore (headstage
    retention clips were removed from drive body design)
    - Remade panel and added labelled fiducial marks as per Filipe's
    requirments
    [eib-64.GBL, eib-64.GBO, eib-64.GBS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]
2019-07-29 Address Filipe's issues with eib-64 prior to fabrication
    - Move mouse bites on panel away from connector since it will be hard to
    sand under there.
    - Reduce ground planes around mouse bites to prvent exposued copper
    after sanding.
    - Adde "Open Ephys" to bottom silk.
    [eib-64.brd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]
2020-02-06 headstage-64 rev. 1.4 along with all dependencies
    - This is headstage-64 revision 1.4. Because it involves a change in the
    bottom analog connector, a lot of other boards had to be changed to
    match the new pinout. That is why there are so many files in this
    commit. Changes in revision 1.4 and affects on other boards are as
    follows:
    1. The coaxial adapter board has been improved to allow a regulator to
    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
    [eib-64.brd, eib-64.sch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]
2020-06-08 Added frozen eib-64/revisions/rev-1.2
    - This is the beta-test revision of the eib
    [eib-64.GBL, eib-64.GBO, eib-64.GBS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]
2021-08-30 Moved eib-64 into a dedicated repository
    - Also, did some cleanup and got rid of lfs
    [eib-64.GBL, eib-64.GBO, eib-64.GBS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]
2022-12-29 Updated the layout with an extra hole for a fiber.
    [eib-64.brd, eib-64.sch]
2022-12-29 Updated the panel with the new layout.
    [eib-64_panel.brd]
2022-12-29 Updated gerber files.
    [copper_bottom_l4.gbr, copper_inner_l2.gbr, copper_inner_l3.gbr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]
2022-12-29 Added centroids for assembly.
2024-03-20 Corrected schematic PDF file.
